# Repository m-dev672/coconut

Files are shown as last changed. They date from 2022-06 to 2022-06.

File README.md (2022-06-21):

## Coconut
It's a keyboard which has 38 keys!</br>
You can use ANSI 104 layout keycaps for this keyboard.

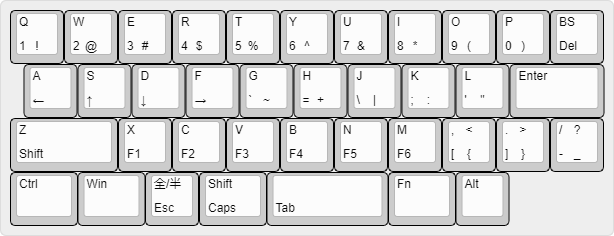
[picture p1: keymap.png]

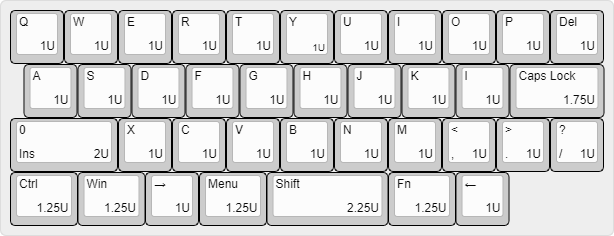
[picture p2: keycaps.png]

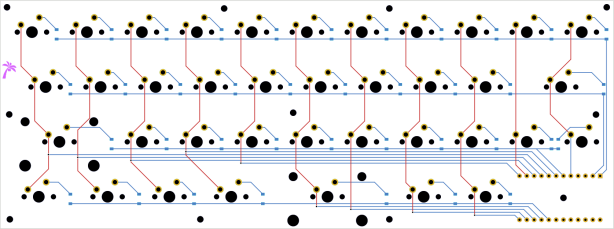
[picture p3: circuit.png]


## Used web site, software and library for this project.
1. http://www.keyboard-layout-editor.com/
2. https://kb.xyz.is/
3. https://msys.qmk.fm/
4. https://kbfirmware.com/
5. https://www.kicad.org/
6. https://github.com/g200kg/kicad-lib-arduino

## LICENCE

```
MIT License

Copyright (c) 2022 Koutarou Mori

Permission is hereby granted, free of charge, to any person obtaining a copy
of this software and associated documentation files (the "Software"), to deal
in the Software without restriction, including without limitation the rights
to use, copy, modify, merge, publish, distribute, sublicense, and/or sell
copies of the Software, and to permit persons to whom the Software is
furnished to do so, subject to the following conditions:

The above copyright notice and this permission notice shall be included in all
copies or substantial portions of the Software.

THE SOFTWARE IS PROVIDED "AS IS", WITHOUT WARRANTY OF ANY KIND, EXPRESS OR
IMPLIED, INCLUDING BUT NOT LIMITED TO THE WARRANTIES OF MERCHANTABILITY,
FITNESS FOR A PARTICULAR PURPOSE AND NONINFRINGEMENT. IN NO EVENT SHALL THE
AUTHORS OR COPYRIGHT HOLDERS BE LIABLE FOR ANY CLAIM, DAMAGES OR OTHER
LIABILITY, WHETHER IN AN ACTION OF CONTRACT, TORT OR OTHERWISE, ARISING FROM,
OUT OF OR IN CONNECTION WITH THE SOFTWARE OR THE USE OR OTHER DEALINGS IN THE
SOFTWARE.
```

This project was developped using a lot of software, etc.</br>
and I couldn't understand license of all.</br>
If there are any infringement, please contact me.

As shown above, this project is basically licensed under MIT license,</br>
but The files in /qmk-firmware and firmware.hex in releases page are licensed under GPL v3 license.

Sharing gerber_nonfree.zip in releases page is prohibited.

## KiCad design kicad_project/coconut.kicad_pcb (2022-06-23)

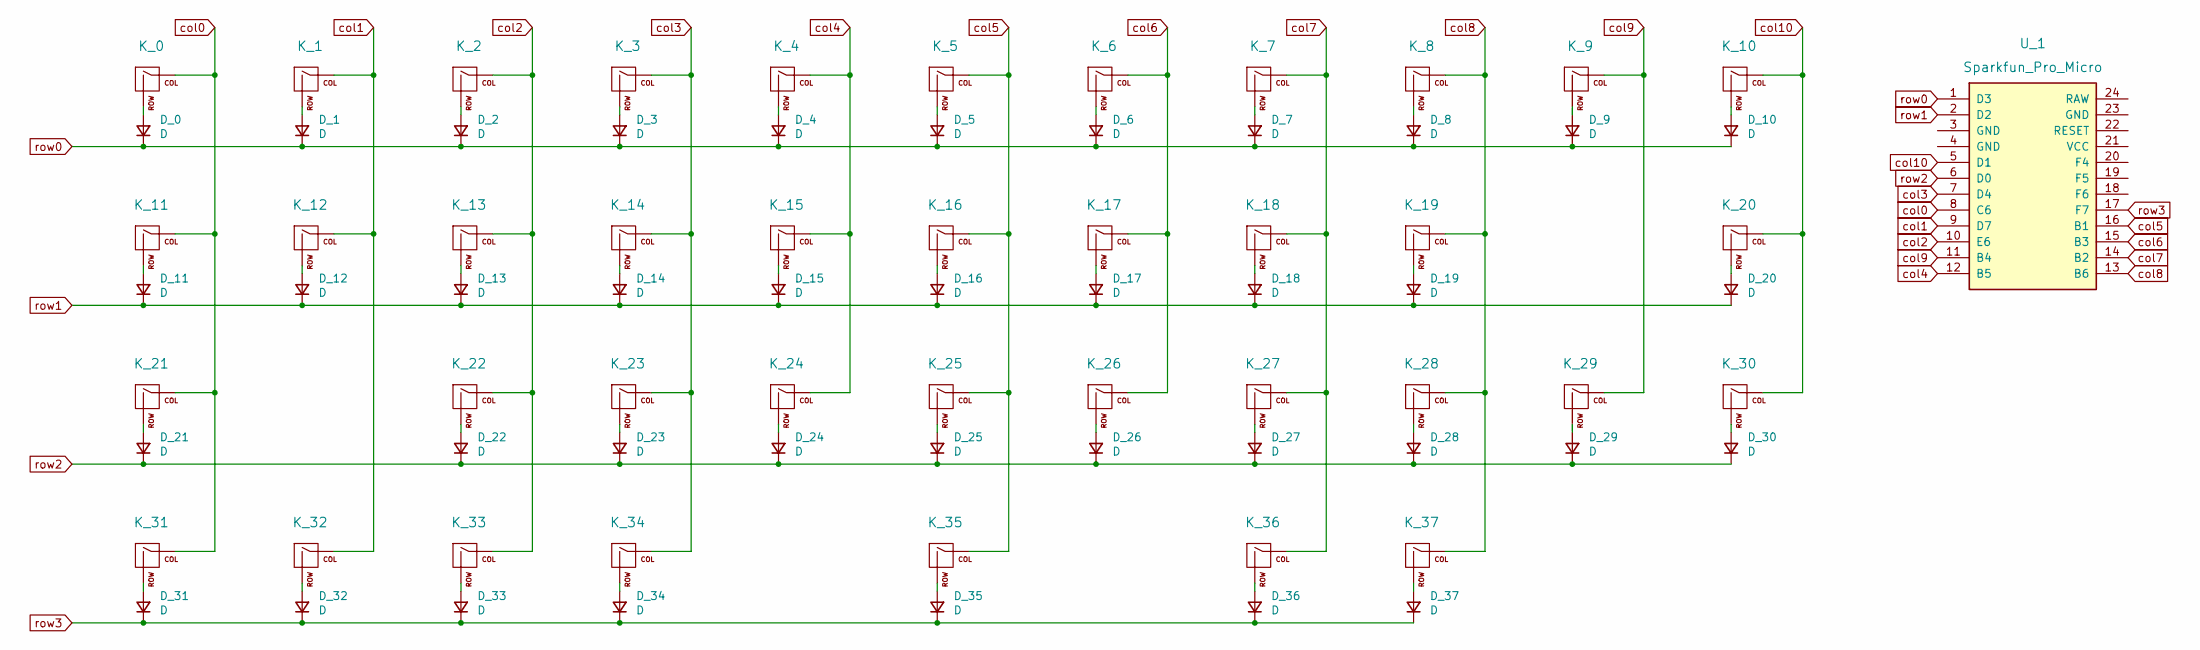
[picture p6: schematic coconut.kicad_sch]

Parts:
D_0, D_1, D_2, D_3, D_4, D_5, D_6, D_7, D_8, D_9, D_10, D_11, D_12, D_13, D_14, D_15, D_16, D_17, D_18, D_19, D_20, D_21, D_22, D_23, D_24, D_25, D_26, D_27, D_28, D_29, D_30, D_31, D_32, D_33, D_34, D_35, D_36, D_37: D; D_SOD-123
K_0, K_1, K_2, K_3, K_4, K_5, K_6, K_7, K_8, K_9, K_10, K_11, K_12, K_13, K_14, K_15, K_16, K_17, K_18, K_19, K_22, K_23, K_24, K_25, K_26, K_27, K_28, K_29, K_30, K_33, K_37: KEYSW; MXOnly-1U-NoLED
K_20: KEYSW; MXOnly-1.75U-NoLED
K_21: KEYSW; MXOnly-2U-NoLED
K_31, K_32, K_34, K_36: KEYSW; MXOnly-1.25U-NoLED
K_35: KEYSW; MXOnly-2.25U-NoLED
U_1: Sparkfun_Pro_Micro

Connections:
unnamed: D_0.2 (A), K_0.2 (ROW)
unnamed: D_1.2 (A), K_1.2 (ROW)
unnamed: D_2.2 (A), K_2.2 (ROW)
unnamed: D_3.2 (A), K_3.2 (ROW)
unnamed: D_4.2 (A), K_4.2 (ROW)
unnamed: D_5.2 (A), K_5.2 (ROW)
unnamed: D_6.2 (A), K_6.2 (ROW)
unnamed: D_7.2 (A), K_7.2 (ROW)
unnamed: D_8.2 (A), K_8.2 (ROW)
unnamed: D_9.2 (A), K_9.2 (ROW)
unnamed: D_10.2 (A), K_10.2 (ROW)
unnamed: D_11.2 (A), K_11.2 (ROW)
unnamed: D_12.2 (A), K_12.2 (ROW)
unnamed: D_13.2 (A), K_13.2 (ROW)
unnamed: D_14.2 (A), K_14.2 (ROW)
unnamed: D_15.2 (A), K_15.2 (ROW)
unnamed: D_16.2 (A), K_16.2 (ROW)
unnamed: D_17.2 (A), K_17.2 (ROW)
unnamed: D_18.2 (A), K_18.2 (ROW)
unnamed: D_19.2 (A), K_19.2 (ROW)
unnamed: D_20.2 (A), K_20.2 (ROW)
unnamed: D_21.2 (A), K_21.2 (ROW)
unnamed: D_22.2 (A), K_22.2 (ROW)
unnamed: D_23.2 (A), K_23.2 (ROW)
unnamed: D_24.2 (A), K_24.2 (ROW)
unnamed: D_25.2 (A), K_25.2 (ROW)
unnamed: D_26.2 (A), K_26.2 (ROW)
unnamed: D_27.2 (A), K_27.2 (ROW)
unnamed: D_28.2 (A), K_28.2 (ROW)
unnamed: D_29.2 (A), K_29.2 (ROW)
unnamed: D_30.2 (A), K_30.2 (ROW)
unnamed: D_31.2 (A), K_31.2 (ROW)
unnamed: D_32.2 (A), K_32.2 (ROW)
unnamed: D_33.2 (A), K_33.2 (ROW)
unnamed: D_34.2 (A), K_34.2 (ROW)
unnamed: D_35.2 (A), K_35.2 (ROW)
unnamed: D_36.2 (A), K_36.2 (ROW)
unnamed: D_37.2 (A), K_37.2 (ROW)
col0: K_0.1 (COL), K_11.1 (COL), K_21.1 (COL), K_31.1 (COL), U_1.8 (C6)
col1: K_1.1 (COL), K_12.1 (COL), K_32.1 (COL), U_1.9 (D7)
col2: K_2.1 (COL), K_13.1 (COL), K_22.1 (COL), K_33.1 (COL), U_1.10 (E6)
col3: K_3.1 (COL), K_14.1 (COL), K_23.1 (COL), K_34.1 (COL), U_1.7 (D4)
col4: K_4.1 (COL), K_15.1 (COL), K_24.1 (COL), U_1.12 (B5)
col5: K_5.1 (COL), K_16.1 (COL), K_25.1 (COL), K_35.1 (COL), U_1.16 (B1)
col6: K_6.1 (COL), K_17.1 (COL), K_26.1 (COL), U_1.15 (B3)
col7: K_7.1 (COL), K_18.1 (COL), K_27.1 (COL), K_36.1 (COL), U_1.14 (B2)
col8: K_8.1 (COL), K_19.1 (COL), K_28.1 (COL), K_37.1 (COL), U_1.13 (B6)
col9: K_9.1 (COL), K_29.1 (COL), U_1.11 (B4)
col10: K_10.1 (COL), K_20.1 (COL), K_30.1 (COL), U_1.5 (D1)
row0: D_0.1 (K), D_1.1 (K), D_2.1 (K), D_3.1 (K), D_4.1 (K), D_5.1 (K), D_6.1 (K), D_7.1 (K), D_8.1 (K), D_9.1 (K), D_10.1 (K), U_1.1 (D3)
row1: D_11.1 (K), D_12.1 (K), D_13.1 (K), D_14.1 (K), D_15.1 (K), D_16.1 (K), D_17.1 (K), D_18.1 (K), D_19.1 (K), D_20.1 (K), U_1.2 (D2)
row2: D_21.1 (K), D_22.1 (K), D_23.1 (K), D_24.1 (K), D_25.1 (K), D_26.1 (K), D_27.1 (K), D_28.1 (K), D_29.1 (K), D_30.1 (K), U_1.6 (D0)
row3: D_31.1 (K), D_32.1 (K), D_33.1 (K), D_34.1 (K), D_35.1 (K), D_36.1 (K), D_37.1 (K), U_1.17 (F7)

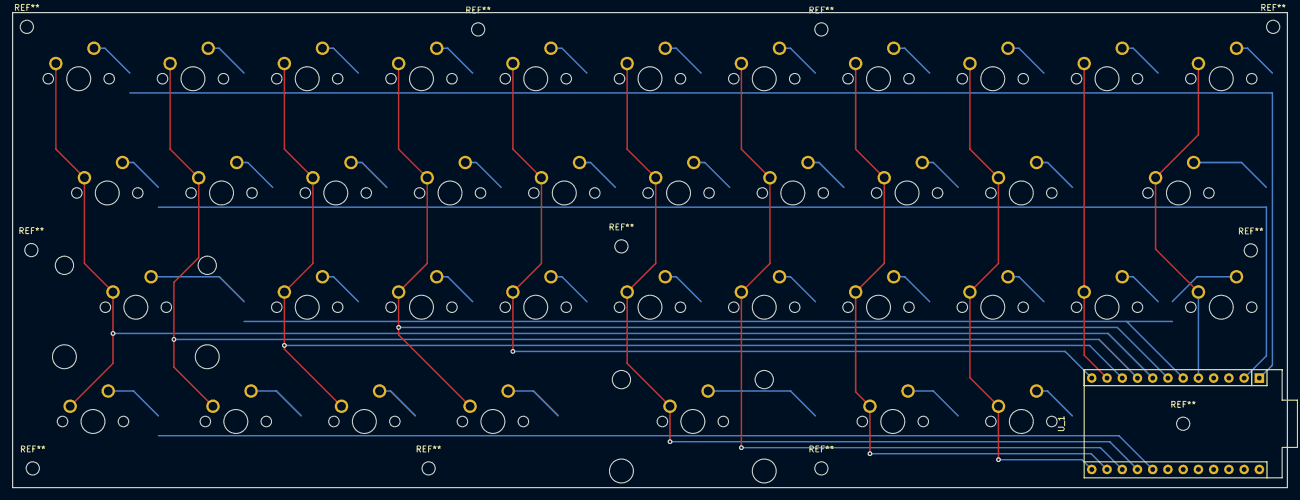
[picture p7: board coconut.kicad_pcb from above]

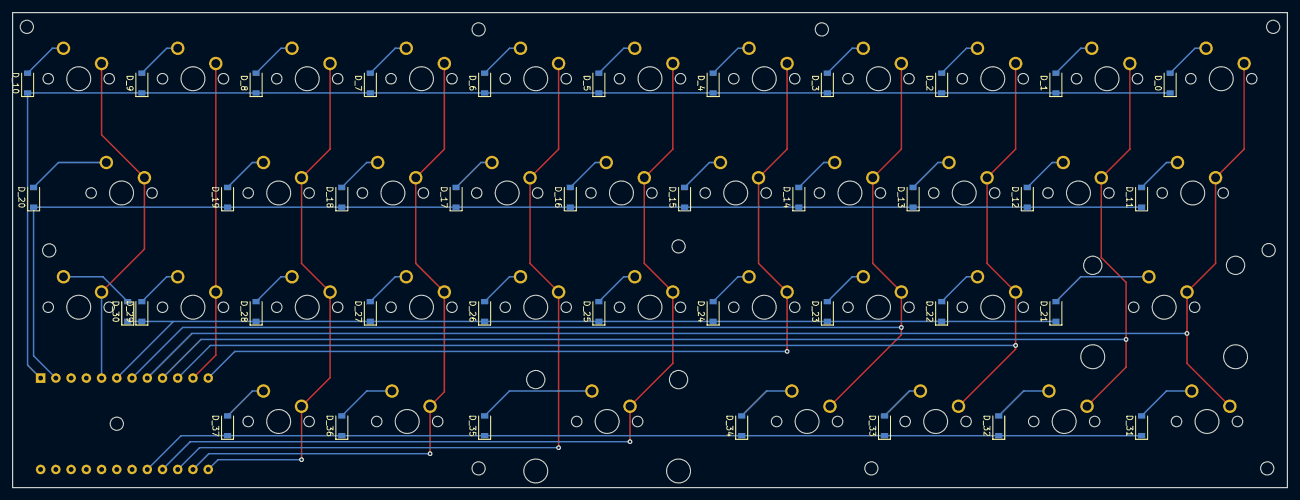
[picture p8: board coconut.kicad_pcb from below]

Board: 2 copper layers, 212.6 x 79.2 mm, 77 parts (38 on the bottom side), 53 nets.

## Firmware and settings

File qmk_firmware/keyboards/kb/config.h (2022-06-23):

#ifndef CONFIG_H
#define CONFIG_H

#include "config_common.h"

/* USB Device descriptor parameter */
#define VENDOR_ID       0xFEED
#define PRODUCT_ID      0x6060
#define DEVICE_VER      0x0001
#define MANUFACTURER    qmkbuilder
#define PRODUCT         keyboard
#define DESCRIPTION     Keyboard

/* key matrix size */
#define MATRIX_ROWS 4
#define MATRIX_COLS 11

/* key matrix pins */
#define MATRIX_ROW_PINS { D3, D2, D0, F7 }
#define MATRIX_COL_PINS { C6, D7, E6, D4, B5, B1, B3, B2, B6, B4, D1 }
#define UNUSED_PINS

/* COL2ROW or ROW2COL */
#define DIODE_DIRECTION COL2ROW

/* number of backlight levels */

#ifdef BACKLIGHT_PIN
#define BACKLIGHT_LEVELS 0
#endif

/* Set 0 if debouncing isn't needed */
#define DEBOUNCING_DELAY 5

/* Mechanical locking support. Use KC_LCAP, KC_LNUM or KC_LSCR instead in keymap */
#define LOCKING_SUPPORT_ENABLE

/* Locking resynchronize hack */
#define LOCKING_RESYNC_ENABLE

/* key combination for command */
#define IS_COMMAND() ( \
    keyboard_report->mods == (MOD_BIT(KC_LSHIFT) | MOD_BIT(KC_RSHIFT)) \
)

/* prevent stuck modifiers */
#define PREVENT_STUCK_MODIFIERS


#ifdef RGB_DI_PIN
#define RGBLIGHT_ANIMATIONS
#define RGBLED_NUM 0
#define RGBLIGHT_HUE_STEP 8
#define RGBLIGHT_SAT_STEP 8
#define RGBLIGHT_VAL_STEP 8
#endif

#endif

#define USB_MAX_POWER_CONSUMPTION 100

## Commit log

2022-06-21 second commit
    [coconut.kicad_pcb, coconut.kicad_sch]
2022-06-21 change the layout
    [coconut.kicad_pcb, coconut.kicad_sch]
2022-06-21 fix mismatch
    [coconut.kicad_pcb, coconut.kicad_sch]
2022-06-21 add clearance
    [coconut.kicad_pcb]
2022-06-23 fix holes
    [coconut.kicad_pcb]
2022-06-23 fix pin assignments
